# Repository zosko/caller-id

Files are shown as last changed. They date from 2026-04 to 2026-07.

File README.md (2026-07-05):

# Caller ID

Caller ID module that can be used in various projects, providing reliable identification of incoming calls along with essential details such as phone numbers, timestamps, and optional contact name resolution. This module ([origin](https://github.com/dilshan/arduino-caller-id)) is designed and modified to be easily integrated into different systems.

## Scheme
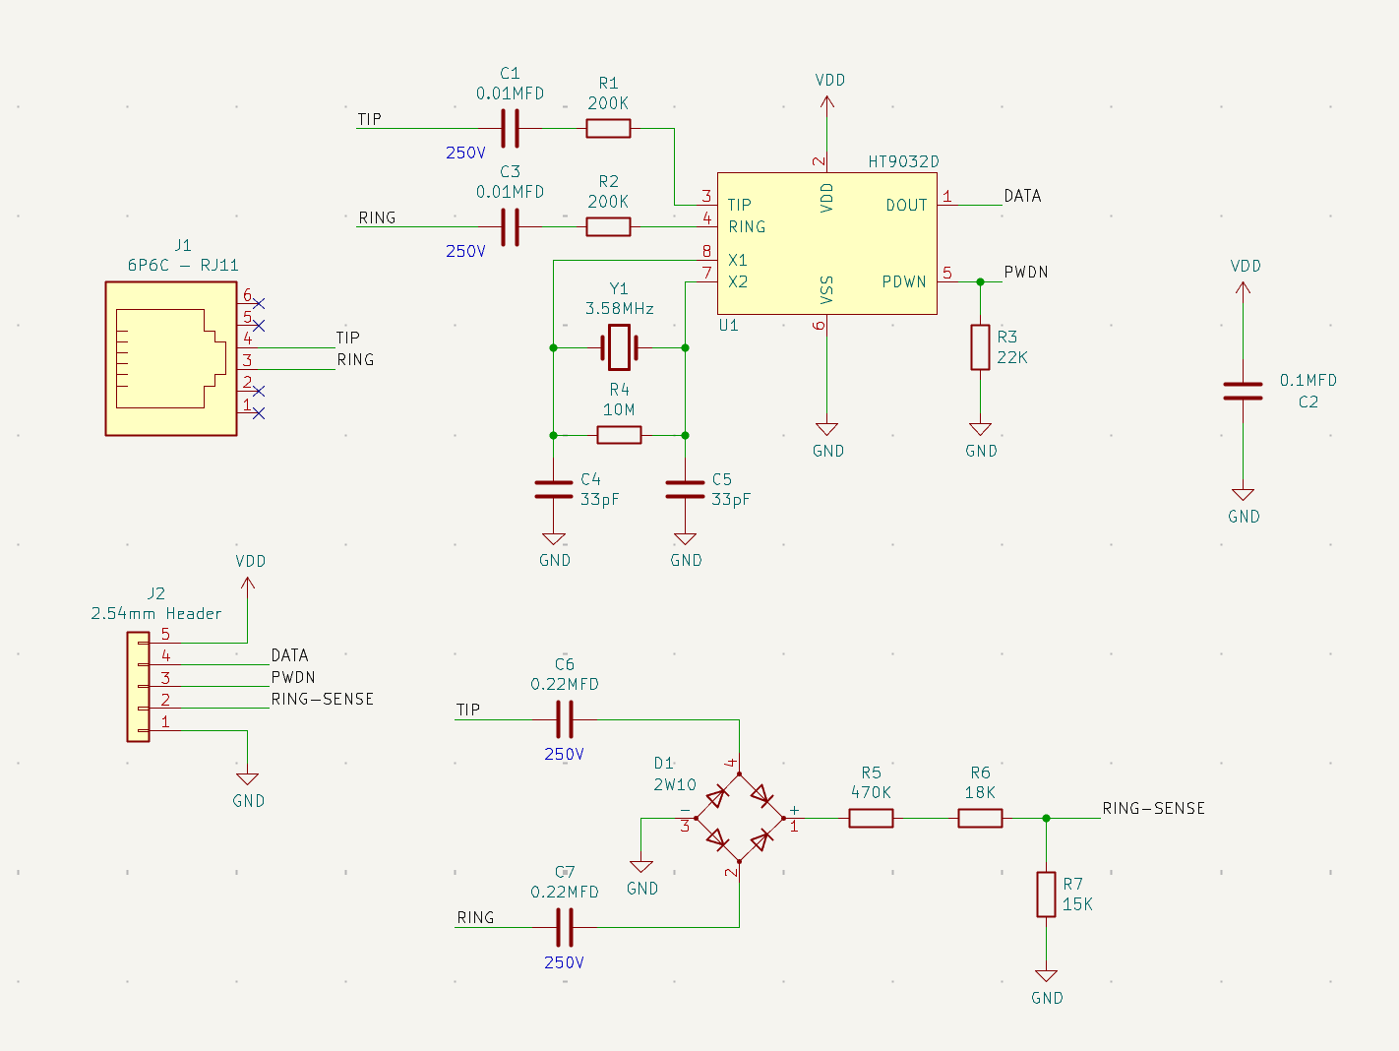
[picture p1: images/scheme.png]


Board | Preview 
-----|-----
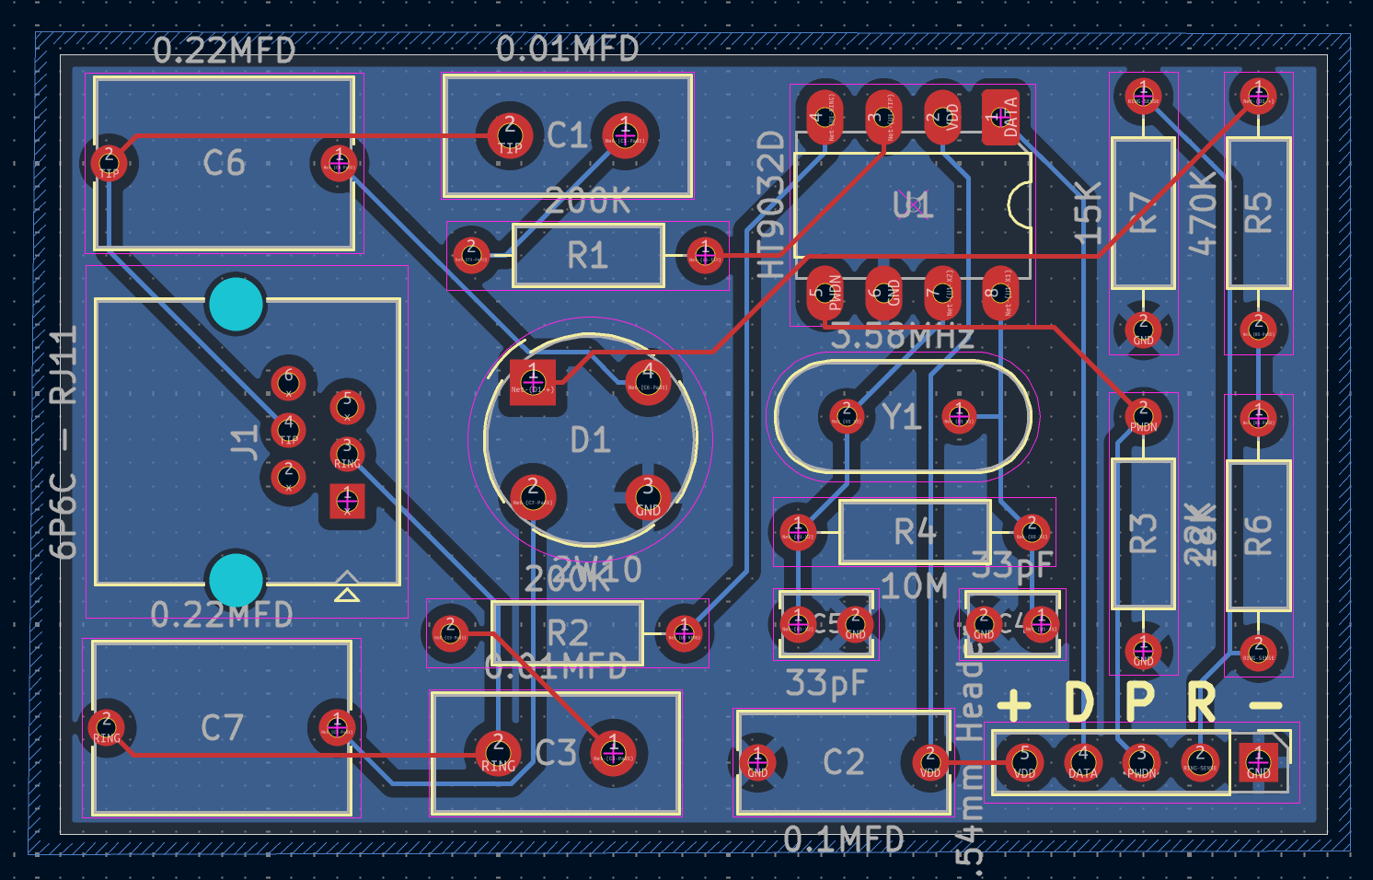
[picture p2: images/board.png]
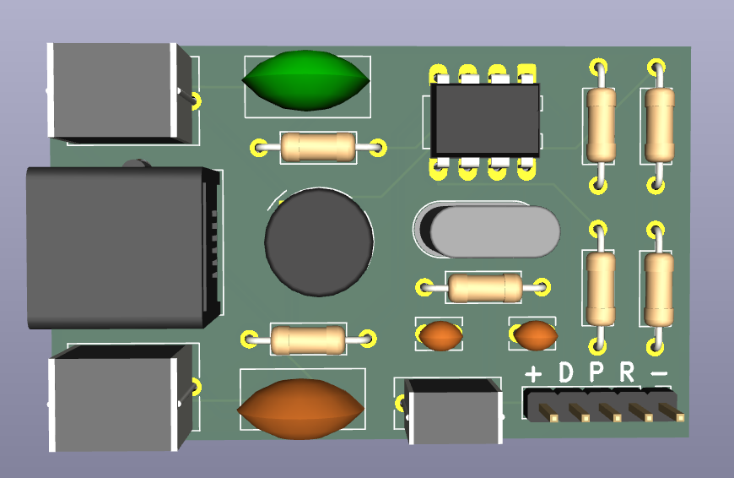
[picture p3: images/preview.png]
|

## Package example

```
INCOMING CALL
MDMF PACKET
 MSG HEADER: 1
 MSG LEN: 8
 MSG END 07050400
Jul0504:00
 MSG HEADER: 2
 MSG LEN: 9
 MSG END 055857857
055857857
 MSG HEADER: 7
 MSG LEN: E
 MSG END Bosko Pet
Bosko Pet
MDMF PACKET END
````

## Sponsorship

PCBWay_logo

**This project is proudly sponsored by [PCBWay](https://pcbway.com).**

PCBWay specializes in manufacturing high-quality printed circuit boards (PCBs), making them accessible and affordable for both hobbyists and professionals.

Their range of services includes:

- PCB prototyping
- Assembly services
- Instant order quotations
- Expert verification processes
- A user-friendly, hassle-free ordering system

I'm sincerely grateful to PCBWay for their generous support in making this project possible.

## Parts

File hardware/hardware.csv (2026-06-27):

Reference | Qty | Value | MFR.Part | JLCPCB Part
C1,C3 | 2 | 0.01uF | MPP103J2G1305085LC | C109484
C2 | 1 | 0.1uF | CT4-0805B104K500F3 | C84772
C4,C5 | 2 | 33pF | CC4-0805N330J500F3 | C94712
C6,C7 | 2 | 0.22uF | CBB21-224J-400V | C914540
D1 | 1 | 2W10 | 2W10G-E4/51 | C266671
J1 | 1 | 6P6C - RJ11 | 520186646 | C588140
J2 | 1 | 2.54mm Header | HX PZ2.54-1x5P ZZ | C32713271
R1,R2 | 2 | 200K | CR1/4W-200K±5%-ST52 | C2894668
R3 | 1 | 22K | CR1/4W-22K±5%-ST52 | C2894673
R4 | 1 | 10M | CR1/4W-10M±5%-ST52 | C2894650
R5 | 1 | 470K | CF1/4W-470KΩ±5% T | C120119
R6 | 1 | 18K | CF1/4W-18KΩ±5% T52 | C120085
R7 | 1 | 15K | CR1/4W-15K±5%-OT26 | C2894540
U1 | 1 | HT9032D | HT9032D(LX) | C22397227
Y1 | 1 | 3.58MHz | X49SD358MSB2SC-1 | C20617999

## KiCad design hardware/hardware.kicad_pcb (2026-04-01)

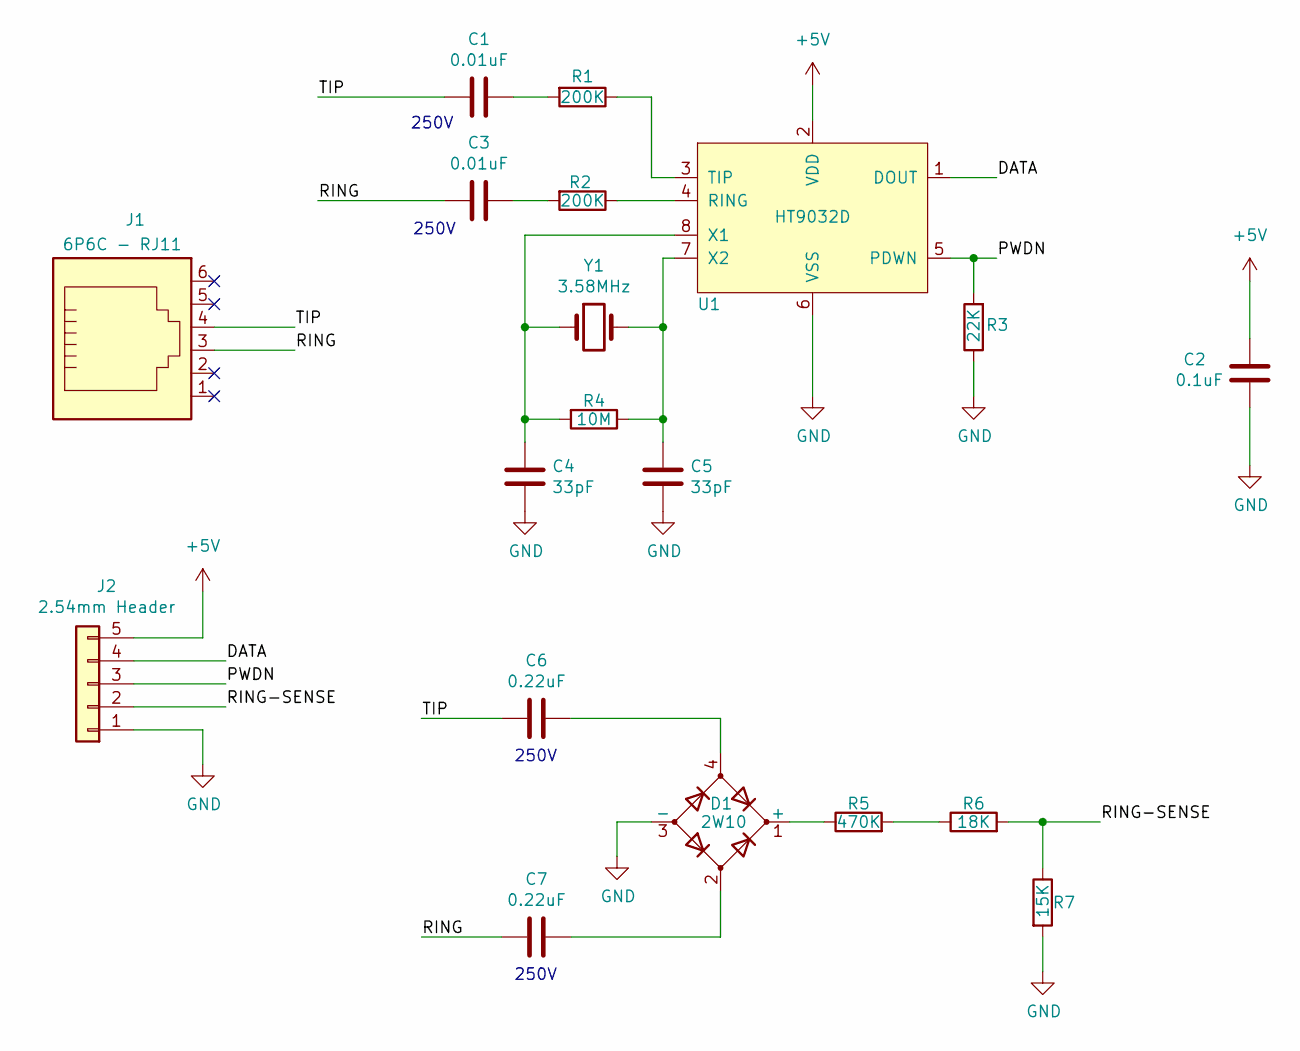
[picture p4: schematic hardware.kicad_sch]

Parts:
C1, C3: 0.01uF; C_Disc_D10.5mm_W5.0mm_P5.00mm; MFR.Part MPP103J2G1305085LC; JLCPCB Part C109484
C2: 0.1uF; C_Rect_L9.0mm_W4.2mm_P7.50mm_MKT; MFR.Part CT4-0805B104K500F3; JLCPCB Part C84772
C4, C5: 33pF; C_Disc_D3.8mm_W2.6mm_P2.50mm; MFR.Part CC4-0805N330J500F3; JLCPCB Part C94712
C6, C7: 0.22uF; C_Rect_L11.0mm_W7.3mm_P10.00mm_MKT; MFR.Part CBB21-224J-400V; JLCPCB Part C914540
D1: 2W10; Diode_Bridge_Round_D9.0mm; MFR.Part 2W10G-E4/51; JLCPCB Part C266671
J1: 6P6C - RJ11; RJ25_Wayconn_MJEA-660X1_Horizontal; MFR.Part 520186646; JLCPCB Part C588140
J2: 2.54mm Header; PinHeader_1x05_P2.54mm_Vertical; MFR.Part HX PZ2.54-1x5P ZZ; JLCPCB Part C32713271
R1, R2: 200K; R_Axial_DIN0207_L6.3mm_D2.5mm_P10.16mm_Horizontal; MFR.Part CR1/4W-200K±5%-ST52; JLCPCB Part C2894668
R3: 22K; R_Axial_DIN0207_L6.3mm_D2.5mm_P10.16mm_Horizontal; MFR.Part CR1/4W-22K±5%-ST52; JLCPCB Part C2894673
R4: 10M; R_Axial_DIN0207_L6.3mm_D2.5mm_P10.16mm_Horizontal; MFR.Part CR1/4W-10M±5%-ST52; JLCPCB Part C2894650
R5: 470K; R_Axial_DIN0207_L6.3mm_D2.5mm_P10.16mm_Horizontal; MFR.Part CF1/4W-470KΩ±5% T; JLCPCB Part C120119
R6: 18K; R_Axial_DIN0207_L6.3mm_D2.5mm_P10.16mm_Horizontal; MFR.Part CF1/4W-18KΩ±5% T52; JLCPCB Part C120085
R7: 15K; R_Axial_DIN0207_L6.3mm_D2.5mm_P10.16mm_Horizontal; MFR.Part CR1/4W-15K±5%-OT26; JLCPCB Part C2894540
U1: HT9032D; DIP-8_W7.62mm_LongPads; MFR.Part HT9032D(LX); JLCPCB Part C22397227
Y1: 3.58MHz; Crystal_HC49-U_Vertical; MFR.Part X49SD358MSB2SC-1; JLCPCB Part C20617999

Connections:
+5V: C2.2, J2.5, U1.2 (VDD)
/DATA: J2.4, U1.1 (DOUT)
/PWDN: J2.3, R3.2, U1.5 (PDWN)
/RING: C3.2, C7.2, J1.3
/RING-SENSE: J2.2, R6.2, R7.1
/TIP: C1.2, C6.2, J1.4
GND: C2.1, C4.2, C5.2, D1.3 (-), J2.1, R3.1, R7.2, U1.6 (VSS)
unnamed: C1.1, R1.2
unnamed: C3.1, R2.2
unnamed: C6.1, D1.4
unnamed: C7.1, D1.2
unnamed: D1.1 (+), R5.1
unnamed: R5.2, R6.1
unnamed: R2.1, U1.4 (RING)
unnamed: R1.1, U1.3 (TIP)
unnamed: C4.1, R4.2, U1.8 (X1), Y1.1
unnamed: C5.1, R4.1, U1.7 (X2), Y1.2

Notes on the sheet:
250V

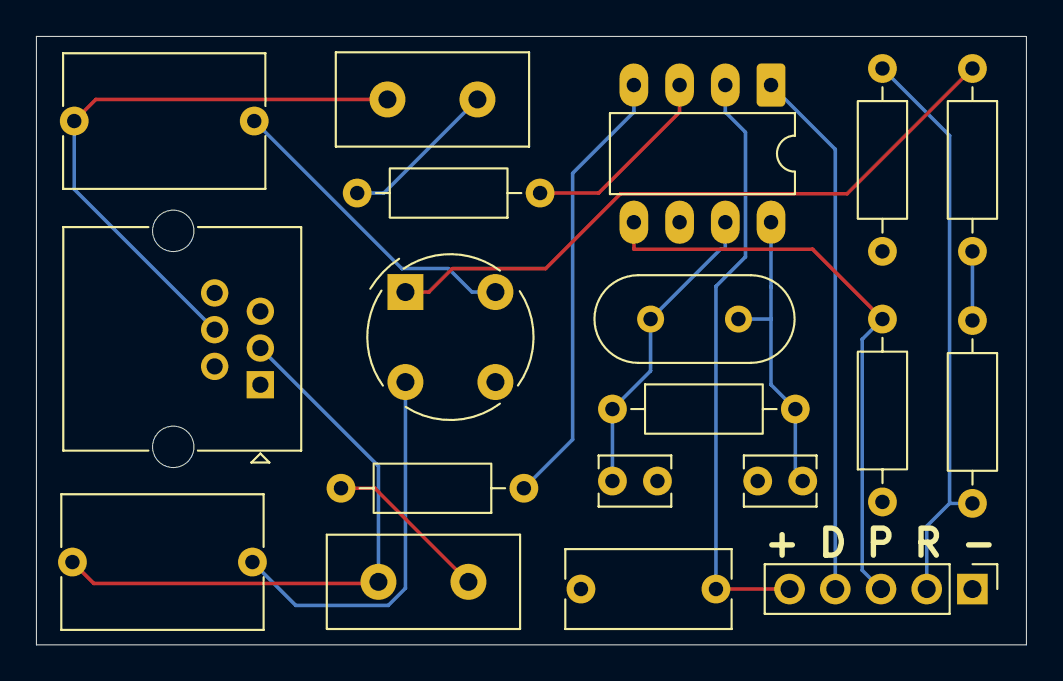
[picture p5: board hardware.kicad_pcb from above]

Board: 2 copper layers, 55.0 x 33.8 mm, 19 parts (0 on the bottom side), 17 nets.

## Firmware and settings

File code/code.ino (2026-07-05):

#include <SoftwareSerial.h>

// + [5v]
// D [10]
// P [9]
// R [8]
// - [GND]

#define CALLER_ID_RX 10
#define CALLER_ID_TX 11

#define RING_DET_PIN 8
#define CLI_PWDN_PIN 9

#define MDMF_HEADER     0x80
#define MDMF_PARAM_TIME 0x01
#define MDMF_PARAM_CID  0x02
#define MDMF_PARAM_NAME 0x07

enum CID_STATE { CID_IDLE,
                 CID_SYNC,
                 CID_PACKET,
                 CID_MESSAGE,
                 CID_END };
enum CID_MSG_STATE { CIDMSG_HEADER,
                     CIDMSG_LEN,
                     CIDMSG_DATA };

SoftwareSerial callerID(CALLER_ID_RX, CALLER_ID_TX);

enum CID_STATE cidState;
enum CID_MSG_STATE cidMsg;

unsigned char tempCount, cidData, packetLen, currLen;
unsigned char msgType, msgLen, msgCurrPos;
unsigned long delayStart, watchdogDelay;
unsigned char lineIdleCounter, watchdogSec;
unsigned char tempInfoPos;

char msgData[16];

void setup() {
  Serial.begin(115200);
  callerID.begin(1200);

  pinMode(RING_DET_PIN, INPUT);
  pinMode(CLI_PWDN_PIN, OUTPUT);
  pinMode(CALLER_ID_RX, INPUT);
  pinMode(CALLER_ID_TX, OUTPUT);

  digitalWrite(CLI_PWDN_PIN, HIGH);

  cidState = CID_IDLE;
  cidMsg = CIDMSG_HEADER;

  resetWatchdog();
}

void loop() {

  if ((cidState == CID_SYNC) || (cidState == CID_PACKET) || (cidState == CID_MESSAGE)) {
    // Watchdog expire-counter increments on every one second.
    if ((micros() - watchdogDelay) >= 1000000) {
      watchdogSec++;
    }

    if (watchdogSec > 10) {
      resetWatchdog();

      cidState = CID_IDLE;
      cidMsg = CIDMSG_HEADER;
      tempCount = 0;
      lineIdleCounter = 0;
      msgCurrPos = 0;

      return;
    }
  }

  if ((cidState == CID_IDLE) && digitalRead(RING_DET_PIN)) {
    Serial.println("INCOMING CALL");

    pinMode(CLI_PWDN_PIN, LOW);
    tempCount = 0;

    resetWatchdog();

    cidState = CID_SYNC;
  } else if (cidState == CID_END) {
    // Caller ID decoding is finished, lets wait until the ringing is finished.
    if ((micros() - delayStart) >= 100000) {
      delayStart = micros();
      lineIdleCounter++;

      resetWatchdog();

      if (digitalRead(RING_DET_PIN)) {
        // Ring signal/session is still active.
        lineIdleCounter = 0;
      }
    }

    // Wait for 8 seconds to start new line sensing session.
    if (lineIdleCounter > 80) {
      // Switch system to the idle state.
      lineIdleCounter = 0;
      cidState = CID_IDLE;
    }
  } else if ((cidState == CID_SYNC) && (callerID.available())) {
    // Process sync data received from callerID and waiting for packet ID.
    cidData = callerID.read();

    resetWatchdog();

    if ((tempCount >= 25) && (cidData == MDMF_HEADER)) {
      Serial.println("MDMF PACKET");
      cidState = CID_PACKET;
      resetWatchdog();
    }

    if (cidData == 0x55) {
      // Sync byte detected, increment the sync data counter.
      tempCount++;
    }
  } else if ((cidState == CID_PACKET) && (callerID.available())) {
    packetLen = callerID.read();
    currLen = 0;
    cidState = CID_MESSAGE;
    cidMsg = CIDMSG_HEADER;

    resetWatchdog();
  } else if ((cidState == CID_MESSAGE) && (callerID.available())) {
    if (currLen >= packetLen) {
      Serial.println("MDMF PACKET END");

      cidState = CID_END;
      cidMsg = CIDMSG_HEADER;

      // Initialize idle state monitoring variables.
      lineIdleCounter = 0;
      delayStart = micros();

      resetWatchdog();

      // Read checksum byte.
      callerID.read();

      // Shutdown caller id decoder.
      pinMode(CLI_PWDN_PIN, HIGH);
      return;
    }

    // Process messages in MDMF packet.
    if (cidMsg == CIDMSG_HEADER) {
      msgType = callerID.read();

      Serial.print(" MSG HEADER: ");
      Serial.println(msgType, HEX);

      cidMsg = CIDMSG_LEN;
      currLen++;

      resetWatchdog();
    } else if (cidMsg == CIDMSG_LEN) {
      msgLen = callerID.read();

      Serial.print(" MSG LEN: ");
      Serial.println(msgLen, HEX);

      cidMsg = CIDMSG_DATA;
      msgCurrPos = 0;
      currLen++;

      resetWatchdog();
    } else if (cidMsg == CIDMSG_DATA) {
      if (msgCurrPos < 15) {
        msgData[msgCurrPos] = callerID.read();
        msgData[msgCurrPos + 1] = 0;
      } else {
        callerID.read();
      }

      msgCurrPos++;
      currLen++;

      if (msgCurrPos >= msgLen) {
        Serial.print(" MSG END ");
        Serial.println(msgData);

        switch (msgType) {
          case MDMF_PARAM_TIME:
            printCallerIDTime();
            break;
          case MDMF_PARAM_CID:
            Serial.println(msgData);
            break;
          case MDMF_PARAM_NAME:
            Serial.println(msgData);
            break;
        }

        cidMsg = CIDMSG_HEADER;

        resetWatchdog();
      }
    }
  } else if (cidState == CID_IDLE) {
    // System and phone line are on idle state.
  }
}

void resetWatchdog() {
  watchdogDelay = micros();
  watchdogSec = 0;
}

void printCallerIDTime() {
  unsigned char month = ((msgData[0] - 0x30) * 10) + (msgData[1] - 0x30);
  char valStr[3];
  String monthStr = "Jan";

  switch (month) {
    case 2:
      monthStr = "Feb";
      break;
    case 3:
      monthStr = "Mar";
      break;
    case 4:
      monthStr = "Apr";
      break;
    case 5:
      monthStr = "May";
      break;
    case 6:
      monthStr = "Jun";
      break;
    case 7:
      monthStr = "Jul";
      break;
    case 8:
      monthStr = "Aug";
      break;
    case 9:
      monthStr = "Sep";
      break;
    case 10:
      monthStr = "Oct";
      break;
    case 11:
      monthStr = "Nov";
      break;
    case 12:
      monthStr = "Dec";
      break;
  }

  Serial.print(monthStr);

  // date
  valStr[0] = msgData[2];
  valStr[1] = msgData[3];
  valStr[2] = 0;

  Serial.print(valStr);

  // hour
  valStr[0] = msgData[4];
  valStr[1] = msgData[5];
  valStr[2] = 0;

  Serial.print(valStr);

  // Print time seperator.
  Serial.print(':');

  //Print minutes
  valStr[0] = msgData[6];
  valStr[1] = msgData[7];
  valStr[2] = 0;

  Serial.println(valStr);
}

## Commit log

2026-04-01 add project
    [hardware.kicad_pcb, hardware.kicad_sch]
2026-06-27 add bom file
    [hardware.csv]
